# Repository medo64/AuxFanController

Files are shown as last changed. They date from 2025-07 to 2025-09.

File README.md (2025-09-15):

# AuxFanController

Allows for PWM control of 4 fans based on the on-board temperature reaading.

Features:
* supports up to 3 fans
* temperature controlled speed
* short startup burst to avoid stall

## PWM Ranges

| Temperature |  PWM |
|:---:|---|
| < 40 °C |  10% |
|  40-80 °C |  10-75% (linear increase) |
| >80 °C | 100% |

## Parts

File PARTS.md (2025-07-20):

## AuxFanController Parts

| | |
|---|---|
| Size | 26.0 x 20.0 mm ~ 0.9 sqin |

### Parts

|  # | Part name | RefDes  | DigiKey PN |
|---:|---|---|---|
|  2 | C 100nF X7R 50V (0805) | C1-C2 | 478-5311-1-ND |
|  1 | C 1uF X7R 25V (0805) | C3 | 1276-1066-1-ND |
|  1 | J MC 1,5/ 2-G-3,81 | J1† | 277-1206-ND -or- 277-1221-ND |
|  3 | J Fan PWM (4w) | J2-J4 | WM4330-ND |
|  1 | U Micro [PIC12F1501] (SOIC-8) | U1 | PIC12F1501-I/SN-ND |
|  1 | U Temperature Analog [MCP9701A] (SOT23-3) | U2 | MCP9701AT-E/TTCT-ND |
|  1 | VR Linear 5V 100mA [AS78L05RTR-E1] (SOT89-3) | VR1 | AS78L05RTR-E1DICT-ND |
|  1 | P Phoenix MC 1,5/ 2-ST-3,81 (2w) | P1 | 277-1161-ND |

† Alternate PN is for vertical variant

### Pin Usage

|  # | Pin | ICSP | Function | Description |
|---:|:---:|---|---|---|
|  1 | Vdd | Vdd  | | |
|  2 | RA5 | | | |
|  3 | RA4 | | PWM3 | Fan 3 Control |
|  4 | RA3 | Vpp  | | |
|  5 | RA2 | | PWM1 | Fan 1 Control |
|  6 | RA1 | Clk  | AN1 | Temperature sensor |
|  7 | RA0 | Dat  | PWM2 | Fan 2 Control |
|  8 | Vss | Vss  | | |

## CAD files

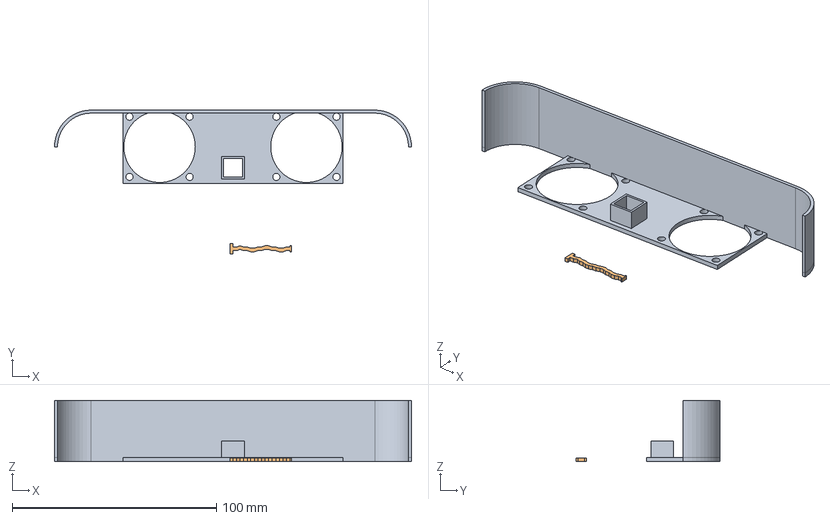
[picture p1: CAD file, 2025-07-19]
design/FanShroud.FCStd
175.0 x 70.5 x 30.0 mm
Double
FlexPin

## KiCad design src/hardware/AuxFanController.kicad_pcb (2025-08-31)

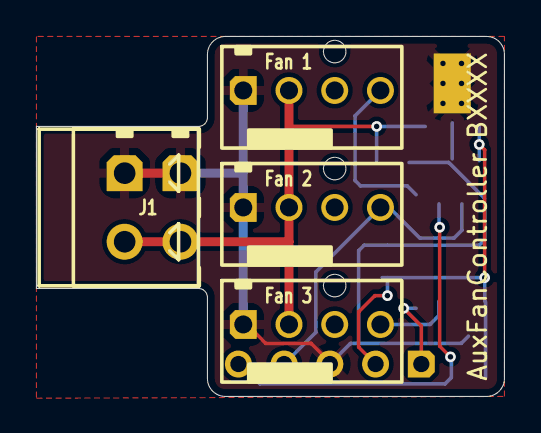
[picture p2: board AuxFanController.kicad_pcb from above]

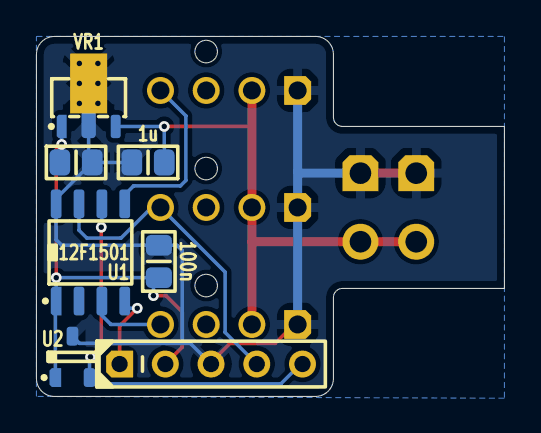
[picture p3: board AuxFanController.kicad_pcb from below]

Board: 2 copper layers, 26.0 x 20.0 mm, 12 parts (7 on the bottom side), 8 nets.

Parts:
C1, C2: 100n; C (0805)
C3: 1u; C (0805)
ICSP: Microchip PIC; ICSP PIC Pogo SS (5w)
J1: MC 1,5/2; J Phoenix MC (2w)
J1': MCV 1,5/2; J Phoenix MCV (2w)
J2: Fan 1; J Molex 047053 [Fan] (4w)
J3: Fan 2; J Molex 047053 [Fan] (4w)
J4: Fan 3; J Molex 047053 [Fan] (4w)
U1: 12F1501; U Micro [PIC12F1501] (SOIC-8)
U2: MCP9701A; U Temperature Analog [MCP9701] (SOT23-3)
VR1: AS78L05RTR; VR Linear 5V 100mA [AS78L05RTR-E1] (SOT89-3')

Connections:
+5V: C1.1, C2.1, ICSP.2, U1.1, U2.1, VR1.1
+12V: C3.1, J1.2, J1'.2, J2.2, J3.2, J4.2, VR1.3
ADC_TEMPERATURE: ICSP.5, U1.6, U2.2
GND: C1.2, C2.2, C3.2, ICSP.3, J1.1, J1'.1, J2.1, J3.1, J4.1, U1.8, U2.3, VR1.2
ICSP_VPP: ICSP.1, U1.4
OUT_PWM1: J2.4, U1.5
OUT_PWM2: ICSP.4, J3.4, U1.7
OUT_PWM3: J4.4, U1.3

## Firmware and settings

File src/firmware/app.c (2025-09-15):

#include <xc.h>
#include <stdbool.h>
#include <stdint.h>
#include "app.h"
#include "adc.h"
#include "pwm.h"

#define SPEED_SPEC_MIN   77  //  30%
#define SPEED_SPEC_MAX  255  // 100%
#define SPEED_USE_MIN    26  //  10%
#define SPEED_USE_MAX   191  //  75%

void startup(void);

void main(void) {
    init();
    pwm_init();
    adc_init();

    startup();

    uint16_t temperatureSum = (uint16_t)(adc_get_temperature()) << 3;  // 8x running average
    while(true) {
        CLRWDT();

        uint8_t temperatureNew = adc_get_temperature();  // measure new temperature
        uint8_t temperatureAvg = (uint8_t)(temperatureSum >> 3);  // take average from previous run
        temperatureSum = (temperatureSum - temperatureAvg) + temperatureNew;  // add new measure in

        uint8_t pwm;
        if (temperatureAvg < 40) {  // minimum fan speed up to 40 °C
            pwm = SPEED_USE_MIN;
        } else if (temperatureAvg < 80) {  // linear increase 40-80 °C
            uint8_t scaleSpeedPerC = (SPEED_USE_MAX - SPEED_USE_MIN) / 40;
            uint8_t scaleT = temperatureAvg - 40;
            pwm = SPEED_USE_MIN + scaleSpeedPerC * scaleT;
        } else {  // max speed if higher than 80 °C
            pwm = SPEED_SPEC_MAX;
        }

        pwm_set_all(pwm);
        __delay_ms(100);  // delay speed changes a bit
    }
}

void startup(void) {
    // each fan:
    // * starts at 30% for 1.5 seconds
    // * goes to full speed for 0.5s
    // * and then goes down to 10%.

    CLRWDT();
    pwm_set_individual(SPEED_SPEC_MIN, 0, 0, 0);
    __delay_ms(500);

    CLRWDT();
    pwm_set_individual(SPEED_SPEC_MIN, SPEED_SPEC_MIN, 0, 0);
    __delay_ms(500);

    CLRWDT();
    pwm_set_individual(SPEED_SPEC_MIN, SPEED_SPEC_MIN, SPEED_SPEC_MIN, 0);
    __delay_ms(500);

    CLRWDT();
    pwm_set_individual(SPEED_SPEC_MAX, SPEED_SPEC_MIN, SPEED_SPEC_MIN, SPEED_SPEC_MIN);
    __delay_ms(500);

    CLRWDT();
    pwm_set_individual(SPEED_USE_MIN, SPEED_SPEC_MAX, SPEED_SPEC_MIN , SPEED_SPEC_MIN);
    __delay_ms(500);

    CLRWDT();
    pwm_set_individual(SPEED_USE_MIN, SPEED_USE_MIN, SPEED_SPEC_MAX, SPEED_SPEC_MIN);
    __delay_ms(500);

    CLRWDT();
    pwm_set_individual(SPEED_USE_MIN, SPEED_USE_MIN, SPEED_USE_MIN, SPEED_SPEC_MAX);
    __delay_ms(500);

    CLRWDT();
    pwm_set_all(SPEED_USE_MIN);
}

void init(void) {
    // Interrupt Control
    GIE = 0;               // Disables all interrupts

    // Oscillator Control
    OSCCON = 0b01111011;   // 16 MHz
}

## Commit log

2025-07-19 Initial commit (move from AuxPower1U)
    [FanController.kicad_pcb, FanController.kicad_sch]
2025-07-19 Refactoring to make board smaller
    [AuxFanController.kicad_pcb, AuxFanController.kicad_sch, FanController.kicad_pcb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]
2025-07-19 Added fan shroud
    [FanShroud.FCStd]
2025-07-19 Updated board refdes
    [AuxFanController.kicad_pcb]
2025-09-15 Fixed minimum spec. speed
    [app.c]
2025-09-15 Adjusted fan curve
